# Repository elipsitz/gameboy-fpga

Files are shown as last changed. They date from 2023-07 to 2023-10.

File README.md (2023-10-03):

# FPGA Game Boy Emulator

This repository contains a Game Boy / Game Boy Color emulator, written in [Chisel](https://www.chisel-lang.org/), that can be run on an FPGA. Read the full writeup [here](https://eli.lipsitz.net/posts/fpga-gameboy-emulator/).

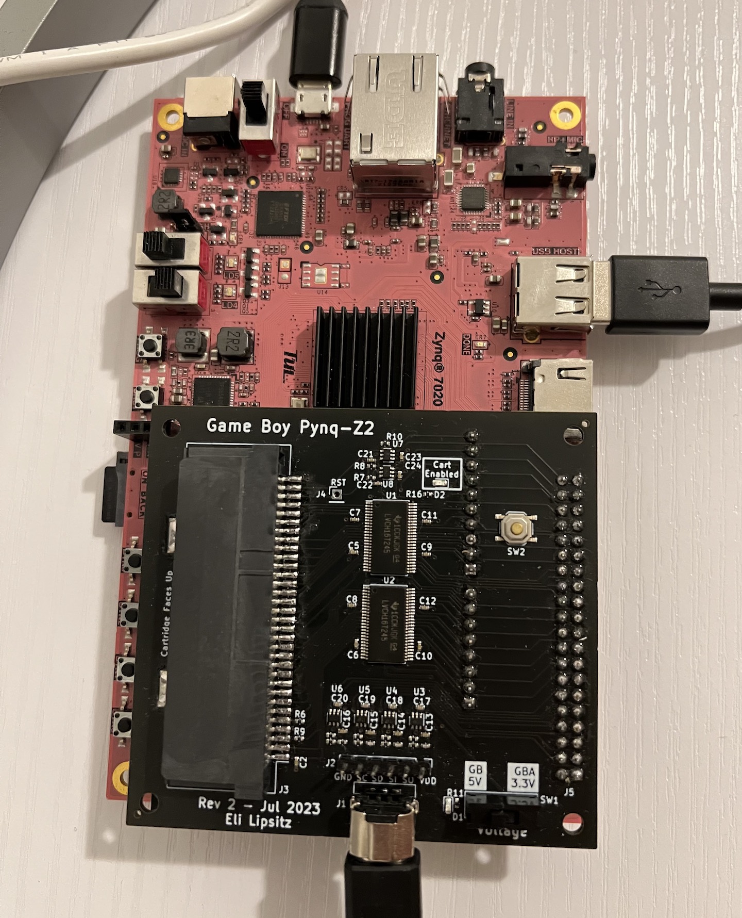
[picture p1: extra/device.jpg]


Currently, only the Pynq-Z2 is supported, although the core of the emulator should be able to be used on any FPGA with sufficient resources.

## Building

A precompiled bitstream is available under Releases.

### Setup

#### Install Vivado

Currently this project uses Vivado 2020.2. The free edition is sufficient. Make sure to install with support for Zynq-7000 SoCs.

Install the [Pynq-Z2 Vivado board files](https://pynq.readthedocs.io/en/latest/overlay_design_methodology/board_settings.html).

Additionally, you should set up a shared IP cache to speed up synthesis of Xilinx IP:
1. Create the `~/vivado_ip_cache` directory (could be located somewhere else).
2. Create the file `~/.Xilinx/Vivado/Vivado_init.tcl`
3. In that file, add `set_param project.defaultIPCacheSetting /home/eli/vivado_ip_cache/` (substituting the absolute path to the IP cache directory).

#### Install other tools

You'll need to install JDK 8 or later, and [Scala Build Tool (`sbt`)](https://www.scala-sbt.org/download.html). Additionally, install [FuseSoC](https://github.com/olofk/fusesoc).

### Building the bitstream

From the top-level directory:

```
fusesoc --cores-root . run --build --target=pynq_z2 elipsitz:gameboy:gameboy
```

This will generate a `.bit` and `.hwh` file, which need to be accessible to the PS Python code.

## Running

### Setup

Install Pynq Linux on the Pynq-Z2, and install the pip packages listed in `python/requirements.txt`.

Transfer the `gameboy_ps` Python module (located in the `python` directory) to the Pynq-Z2.

Place the `gameboy.bit` and `gameboy.hwh` files from the build process in the `gameboy_ps/resources` directory.

### HDMI and Controller

Connect an HDMI cable from the "HDMI OUT" port on the Pynq-Z2 to a monitor or TV.

Attach an Xbox-compatible controller to the USB port of the Pynq-Z2.

### Running 

As root, run `python3 -m gameboy_ps <path to ROM directory>`, passing the path to the directory containing ROM files.

The program will load the bitstream to the PL. It takes a few seconds to load all of the Pynq libraries, but the main menu should soon show up on the display.

Warning: the audio output can be quite loud. Start at the lowest setting on the monitor/TV and increase it as needed.

## Building the cartridge adapter board

To play physical cartridges, you'll need to assemble the adapter board. KiCad board files can be found in the `pcb/pynq_adapter_rev2` directory. The schematic is pre-populated with LCSC part numbers for easy assembly at JLCPCB.

You'll need to add a few components yourself. These are all easy to solder:

* A 2x20 0.1mm female pin header (e.g. [this one](https://www.adafruit.com/product/2222)). These are used for Raspberry Pi HATs, so they're pretty easy to find.
* A SPDT slide switch such as the [EG1218](https://octopart.com/search?q=EG1218), or just a 1x3 strip of 0.1mm male pin header and a jumper.
* A GBA SP slot (such as [this one](https://handheldlegend.com/products/game-boy-cartridge-slot)). These can be found quite cheaply on eBay or Aliexpress as well. They're all pretty much the same.
* If desired, a GBA link port (e.g. [this one](https://handheldlegend.com/products/game-boy-advance-ext-link-port)). These can also be found easily from other sources.

The other parts are relatively small, so I don't recommend hand soldering the board. However, if you want to assemble the whole thing yourself, in addition to assorted resistors and capacitors, you'll also need:

* 6x [74LVC1T45DCK](https://octopart.com/search?q=74LVC1T45DCK) 1-bit level shifters.
* 2x [74LVCH16T245DGGR](https://octopart.com/search?q=74LVCH16T245DGGR) 16-bit level shifters. The non 'H' version should work as well, but the 'H' (bus hold) version is preferable.

## Appendix

### Getting Xbox controller to work on Pynq-Z2

This needs the `xpad` and `joydev` drivers. Pynq Linux isn't built with them. If you're running Pynq Linux with kernel `5.15.19-xilinx-v2022.1`, prebuilt kernel modules can be found in the `extra` directory in the repository. Otherwise, to build loadable kernel modules from scratch:

On the Pynq-Z2, go to `/lib/modules/5.15.19-xilinx-v2022.1/build`.

Download the right version of [`xpad.c`](https://raw.githubusercontent.com/torvalds/linux/v5.15/drivers/input/joystick/xpad.c)
to `drivers/input/joystick/xpad.c`.

And do the same with [`joydev.c`](https://raw.githubusercontent.com/torvalds/linux/v5.15/drivers/input/joydev.c), to `drivers/input/joydev.c`.

The build commands in `/lib/modules` need to run with `sudo` due to permissions issues.

Do `sudo make menuconfig` and set:

* `Device Drivers --> Input device support --> Joystick interface` to `M` (for 'module')
* `Device Drivers --> Input device support --> Joysticks/gamepads --> X-box Gamepad support` to `M` (for 'module')

Save and exit.

Then build the modules:

```
sudo make scripts
sudo make distclean
sudo make prepare
sudo make modules_prepare

sudo make -C . M=drivers/input/ joydev.ko
sudo make -C . M=drivers/input/joystick xpad.ko
```

Install the modules so that they'll be loaded automatically on boot.
Copy the `.ko` files to `/usr/lib/modules/$(uname -r)/kernel/`, and append
to `/etc/modules`:

```
joydev
xpad
```

Alternatively, use `insmod <modules>.ko` to load them once.

Make sure the `xilinx` user is in the group `input`:
`sudo usermod -a -G input xilinx` (and re-login)

Install the Python library with `sudo pip3 install xbox360controller`

Create the device nodes if needed: https://docs.kernel.org/input/joydev/joystick.html#device-nodes

```
cd /dev
rm js*
mkdir input
mknod input/js0 c 13 0
mknod input/js1 c 13 1
mknod input/js2 c 13 2
mknod input/js3 c 13 3
ln -s input/js0 js0
ln -s input/js1 js1
ln -s input/js2 js2
ln -s input/js3 js3
```

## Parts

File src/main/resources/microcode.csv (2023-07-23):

Label | Comment | Encoding | PcNext | IME | RegRead1Sel | RegRead2Sel | RegWriteSel | RegOp | IncOp | IncReg | AluOp | AluSelA | AluSelB | AluFlagSet | MemEn | MemWr | MemAddrSel | MicroBranch | NextState
NOP |  | 00000000 | - | = | - | - | - | None | - | - | - | - | - | No | - | - | - | Fetch | -
_INVALID |  |  | Same | = | - | - | - | None | No | - | - | - | - | No | No | - | - | Jump | _INVALID
HALT |  | 01110110 | Same | = | - | - | - | None | No | - | - | - | - | No | No | - | - | Jump | HALT
STOP |  | 00010000 | IncOut | = | - | - | - | None | Inc | PC | - | - | - | No | No | - | - | Next | -
#STOP_loop |  |  | Same | = | - | - | - | None | No | - | - | - | - | No | No | - | - | Jump | #STOP_loop
LD r, (HL) |  | 01???110 | Same | = | - | - | Reg8Dest | WriteMem | No | HL | - | - | - | No | Yes | No | Incrementer | Jump | NOP
LD (HL), r |  | 01110??? | Same | = | - | Reg8Src | - | None | No | HL | CopyB | - | Reg2 | No | Yes | Yes | Incrementer | Jump | NOP
LD (HL),n |  | 00110110 | IncOut | = | - | - | W | WriteMem | Inc | PC | - | - | - | No | Yes | No | Incrementer | Next | -
 |  |  | Same | = | - | W | - | None | No | HL | CopyB | - | Reg2 | No | Yes | Yes | Incrementer | Jump | NOP
LD r,r |  | 01?????? | - | = | - | Reg8Src | Reg8Dest | WriteAlu | - | - | CopyB | - | Reg2 | No | - | - | - | Fetch | -
LD r,n |  | 00???110 | IncOut | = | - | - | Reg8Dest | WriteMem | Inc | PC | - | - | - | No | Yes | No | Incrementer | Jump | NOP
LD rr,nn |  | 00??0001 | IncOut | = | - | - | Reg16Lo | WriteMem | Inc | PC | - | - | - | No | Yes | No | Incrementer | Next | -
 |  |  | IncOut | = | - | - | Reg16Hi | WriteMem | Inc | PC | - | - | - | No | Yes | No | Incrementer | Jump | NOP
ldi (HL),A |  | 00100010 | Same | = | - | - | - | None | Inc | HL | CopyA | A | - | No | Yes | Yes | Incrementer | Jump | NOP
ldi A,(HL) |  | 00101010 | Same | = | - | - | A | WriteMem | Inc | HL | - | - | - | No | Yes | No | Incrementer | Jump | NOP
ldd (HL),A |  | 00110010 | Same | = | - | - | - | None | Dec | HL | CopyA | A | - | No | Yes | Yes | Incrementer | Jump | NOP
ldd A,(HL) |  | 00111010 | Same | = | - | - | A | WriteMem | Dec | HL | - | - | - | No | Yes | No | Incrementer | Jump | NOP
ALU A, n |  | 11???110 | IncOut | = | - | - | W | WriteMem | Inc | PC | - | - | - | No | Yes | No | Incrementer | Next | -
 |  |  | - | = | - | W | A | WriteAlu | - | - | InstAlu | A | Reg2 | All | - | - | - | Fetch | -
ALU A, (HL) |  | 10???110 | Same | = | - | - | W | WriteMem | No | HL | - | - | - | No | Yes | No | Incrementer | Next | -
 |  |  | - | = | - | W | A | WriteAlu | - | - | InstAlu | A | Reg2 | All | - | - | - | Fetch | -
ALU A, r |  | 10?????? | - | = | - | Reg8Src | A | WriteAlu | - | - | InstAlu | A | Reg2 | All | - | - | - | Fetch | -
JP nn | little endian address | 11000011 | IncOut | = | - | - | Z | WriteMem | Inc | PC | - | - | - | No | Yes | No | Incrementer | Next | -
 |  |  | IncOut | = | - | - | W | WriteMem | Inc | PC | - | - | - | No | Yes | No | Incrementer | Next | -
#PC=WZ |  |  | IncOut | = | - | - | - | None | No | WZ | - | - | - | No | No | - | - | Jump | NOP
JP HL |  | 11101001 | IncOut | = | - | - | - | None | IncNoWrite | HL | - | - | - | No | - | - | Incrementer | Fetch* | -
JP f,nn | Conditional | 110??010 | IncOut | = | - | - | Z | WriteMem | Inc | PC | - | - | - | No | Yes | No | Incrementer | Next | -
 |  |  | IncOut | = | - | - | W | WriteMem | Inc | PC | - | - | - | No | Yes | No | Incrementer | Cond | #PC=WZ
 |  |  | - | = | - | - | - | None | - | - | - | - | - | No | - | - | - | Fetch | -
LD (rr), A |  | 00??0010 | Same | = | - | - | - | None | No | Inst16 | CopyA | A | - | No | Yes | Yes | Incrementer | Jump | NOP
LD A, (rr) |  | 00??1010 | Same | = | - | - | A | WriteMem | No | Inst16 | - | - | - | No | Yes | No | Incrementer | Jump | NOP
LD (nn), A |  | 11101010 | IncOut | = | - | - | Z | WriteMem | Inc | PC | - | - | - | No | Yes | No | Incrementer | Next | -
 |  |  | IncOut | = | - | - | W | WriteMem | Inc | PC | - | - | - | No | Yes | No | Incrementer | Next | -
 |  |  | Same | = | - | - | - | None | No | WZ | CopyA | A | - | No | Yes | Yes | Incrementer | Jump | NOP
LD A, (nn) |  | 11111010 | IncOut | = | - | - | Z | WriteMem | Inc | PC | - | - | - | No | Yes | No | Incrementer | Next | -
 |  |  | IncOut | = | - | - | W | WriteMem | Inc | PC | - | - | - | No | Yes | No | Incrementer | Next | -
 |  |  | Same | = | - | - | A | WriteMem | No | WZ | - | - | - | No | Yes | No | Incrementer | Jump | NOP
LD (FF00 + n), A |  | 11100000 | IncOut | = | - | - | W | WriteMem | Inc | PC | - | - | - | No | Yes | No | Incrementer | Next | -
 |  |  | Same | = | - | W | - | None | No | - | CopyA | A | - | No | Yes | Yes | High | Jump | NOP
LD (FF00 + C), A |  | 11100010 | Same | = | - | C | - | None | No | - | CopyA | A | - | No | Yes | Yes | High | Jump | NOP
LD A, (FF00 + n) |  | 11110000 | IncOut | = | - | - | W | WriteMem | Inc | PC | - | - | - | No | Yes | No | Incrementer | Next | -
 |  |  | Same | = | - | W | A | WriteMem | No | - | - | - | - | No | Yes | No | High | Jump | NOP
LD A, (FF00 + C) |  | 11110010 | Same | = | - | C | A | WriteMem | No | - | - | - | - | No | Yes | No | High | Jump | NOP
INC rr |  | 00??0011 | Same | = | - | - | - | None | Inc | Inst16 | - | - | - | No | No | - | - | Jump | NOP
DEC rr |  | 00??1011 | Same | = | - | - | - | None | Dec | Inst16 | - | - | - | No | No | - | - | Jump | NOP
LD (nn), SP |  | 00001000 | IncOut | = | - | - | Z | WriteMem | Inc | PC | - | - | - | No | Yes | No | Incrementer | Next | -
 |  |  | IncOut | = | - | - | W | WriteMem | Inc | PC | - | - | - | No | Yes | No | Incrementer | Next | -
 |  |  | Same | = | - | SP_Lo | - | None | Inc | WZ | CopyB | - | Reg2 | No | Yes | Yes | Incrementer | Next | -
 |  |  | Same | = | - | SP_Hi | - | None | Inc | WZ | CopyB | - | Reg2 | No | Yes | Yes | Incrementer | Jump | NOP
LD SP, HL |  | 11111001 | Same | = | - | L | SP_Lo | WriteAlu | No | - | CopyB | - | Reg2 | No | No | - | - | Next | -
 |  |  | - | = | - | H | SP_Hi | WriteAlu | - | - | CopyB | - | Reg2 | No | - | - | - | Fetch | -
PUSH AF |  | 11110101 | Same | = | - | - | - | None | Dec | SP | - | - | - | No | No | No | - | Next | -
 |  |  | Same | = | - | A | - | None | Dec | SP | CopyB | - | Reg2 | No | Yes | Yes | Incrementer | Next | -
 |  |  | Same | = | - | F | - | None | No | SP | CopyB | - | Reg2 | No | Yes | Yes | Incrementer | Jump | NOP
POP AF |  | 11110001 | Same | = | - | - | F | WriteMem | Inc | SP | CopyB | - | Reg2 | No | Yes | No | Incrementer | Next | -
 |  |  | Same | = | - | - | A | WriteMem | Inc | SP | CopyB | - | Reg2 | No | Yes | No | Incrementer | Jump | NOP
PUSH rr |  | 11??0101 | Same | = | - | - | - | None | Dec | SP | - | - | - | No | No | No | - | Next | -
 |  |  | Same | = | - | Reg16Hi | - | None | Dec | SP | CopyB | - | Reg2 | No | Yes | Yes | Incrementer | Next | -
 |  |  | Same | = | - | Reg16Lo | - | None | No | SP | CopyB | - | Reg2 | No | Yes | Yes | Incrementer | Jump | NOP
POP rr |  | 11??0001 | Same | = | - | - | Reg16Lo | WriteMem | Inc | SP | - | - | - | No | Yes | No | Incrementer | Next | -
 |  |  | Same | = | - | - | Reg16Hi | WriteMem | Inc | SP | - | - | - | No | Yes | No | Incrementer | Jump | NOP
ADD HL,rr | 16-bit add | 00??1001 | Same | = | L | Reg16Lo | L | WriteAlu | No | - | AddLo | Reg1 | Reg2 | No | No | - | - | Next | -
 |  |  | - | = | H | Reg16Hi | H | WriteAlu | - | - | AddHi | Reg1 | Reg2 | -*** | - | - | - | Fetch | -
ADD SP,dd |  | 11101000 | IncOut | = | - | - | W | WriteMem | Inc | PC | - | - | - | No | Yes | No | Incrementer | Next | -
 |  |  | Same | = | SP_Lo | W | SP_Lo | WriteAlu | No | - | AddLo | Reg1 | Reg2 | 0*** | No | - | - | Next | -
 |  |  | Same | = | SP_Hi | W | SP_Hi | WriteAlu | No | - | AddHi | Reg1 | SignReg2 | No | No | - | - | Jump | NOP
ld HL,SP+dd |  | 11111000 | IncOut | = | - | - | W | WriteMem | Inc | PC | - | - | - | No | Yes | No | Incrementer | Next | -
 |  |  | Same | = | SP_Lo | W | L | WriteAlu | No | - | AddLo | Reg1 | Reg2 | 0*** | No | - | - | Next | -
 |  |  | - | = | SP_Hi | W | H | WriteAlu | - | - | AddHi | Reg1 | SignReg2 | No | - | - | - | Fetch | -
JR e |  | 00011000 | IncOut | = | - | - | W | WriteMem | Inc | PC | - | - | - | No | Yes | No | Incrementer | Next | -
#PC+=W |  |  | Same | = | PC_Lo | W | PC_Lo | WriteAlu | No | - | AddLo | Reg1 | Reg2 | No | No | - | - | Next | -
 | Mem MemAddr to be the new PC, and need to increment PC |  | IncOut | = | PC_Hi | W | PC_Hi | WriteAlu | IncNoWrite | PC_ALU | AddHi | Reg1 | SignReg2 | No | Yes | No | Incrementer | Fetch* | -
JR c,e | Conditional | 001??000 | IncOut | = | - | - | W | WriteMem | Inc | PC | - | - | - | No | Yes | No | Incrementer | Cond | #PC+=W
 |  |  | - | = | - | - | - | None | - | - | - | - | - | No | - | - | - | Fetch | -
CALL nn |  | 11001101 | IncOut | = | - | - | Z | WriteMem | Inc | PC | - | - | - | No | Yes | No | Incrementer | Next | -
 |  |  | IncOut | = | - | - | W | WriteMem | Inc | PC | - | - | - | No | Yes | No | Incrementer | Next | -
#CALL_end |  |  | Same | = | - | - | - | None | Dec | SP | - | - | - | No | No | No | - | Next | -
 |  |  | Same | = | - | PC_Hi | - | None | Dec | SP | CopyB | - | Reg2 | No | Yes | Yes | Incrementer | Next | -
 |  |  | Same | = | - | PC_Lo | - | None | No | SP | CopyB | - | Reg2 | No | Yes | Yes | Incrementer | Next | -
 |  |  | IncOut | = | - | - | - | None | IncNoWrite | WZ | - | - | - | No | - | - | Incrementer | Fetch* | -
CALL cc, nn | Conditional | 110??100 | IncOut | = | - | - | Z | WriteMem | Inc | PC | - | - | - | No | Yes | No | Incrementer | Next | -
 |  |  | IncOut | = | - | - | W | WriteMem | Inc | PC | - | - | - | No | Yes | No | Incrementer | Cond | #CALL_end
 |  |  | - | = | - | - | - | None | - | - | - | - | - | No | - | - | - | Fetch | -
RET |  | 11001001 | Same | = | - | - | PC_Lo | WriteMem | Inc | SP | - | - | - | No | Yes | No | Incrementer | Next | -
 |  |  | Same | = | - | - | PC_Hi | WriteMem | Inc | SP | - | - | - | No | Yes | No | Incrementer | Next | -
 | Extra NOP |  | Same | = | - | - | - | None | No | - | - | - | - | No | No | - | - | Jump | NOP
RET cc | Conditional | 110??000 | Same | = | - | - | - | None | No | - | - | - | - | No | No | - | - | Cond | RET
 |  |  | - | = | - | - | - | None | - | - | - | - | - | No | - | - | - | Fetch | -
RETI | RET + enable interrupts | 11011001 | Same | = | - | - | PC_Lo | WriteMem | Inc | SP | - | - | - | No | Yes | No | Incrementer | Next | -
 |  |  | Same | = | - | - | PC_Hi | WriteMem | Inc | SP | - | - | - | No | Yes | No | Incrementer | Next | -
 | Extra NOP |  | Same | En | - | - | - | None | No | - | - | - | - | No | No | - | - | Jump | NOP
INC (HL) |  | 00110100 | Same | = | - | - | W | WriteMem | No | HL | - | - | - | No | Yes | No | Incrementer | Next | -
 |  |  | Same | = | - | W | - | None | No | HL | IncB | - | Reg2 | All | Yes | Yes | Incrementer | Jump | NOP
INC r |  | 00???100 | - | = | - | Reg8Dest | Reg8Dest | WriteAlu | - | - | IncB | - | Reg2 | All | - | - | - | Fetch | -
DEC (HL) |  | 00110101 | Same | = | - | - | W | WriteMem | No | HL | - | - | - | No | Yes | No | Incrementer | Next | -
 |  |  | Same | = | - | W | - | None | No | HL | DecB | - | Reg2 | All | Yes | Yes | Incrementer | Jump | NOP
DEC r |  | 00???101 | - | = | - | Reg8Dest | Reg8Dest | WriteAlu | - | - | DecB | - | Reg2 | All | - | - | - | Fetch | -
ALU unary | accumulator/flag ops | 00???111 | - | = | - | - | A | WriteAlu | - | - | InstAcc | A | Reg2 | All | - | - | - | Fetch | -
CB_PREFIX | CB prefix | 11001011 | IncOut | = | - | - | - | None | Inc | PC | - | - | - | No | Yes | No | Incrementer | DispatchCB | -
CB_ALU (HL) | CB shift / rotates | CB_00???110 | Same | = | - | - | W | WriteMem | No | HL | - | - | - | No | Yes | No | Incrementer | Next | -
 |  |  | Same | = | - | W | - | None | No | HL | InstCB | - | Reg2 | All | Yes | Yes | Incrementer | Jump | NOP
CB_ALU r | CB shift / rotates | CB_00?????? | - | = | - | Reg8Src | Reg8Src | WriteAlu | - | - | InstCB | - | Reg2 | All | - | - | - | Fetch | -
BIT (HL) | No (HL) writeback | CB_01???110 | Same | = | - | - | W | WriteMem | No | HL | - | - | - | No | Yes | No | Incrementer | Next | -
 |  |  | - | = | - | W | - | None | - | - | InstBit | - | Reg2 | All | - | - | - | Fetch | -
CB_BIT (HL) |  | CB_?????110 | Same | = | - | - | W | WriteMem | No | HL | - | - | - | No | Yes | No | Incrementer | Next | -
 |  |  | Same | = | - | W | - | None | No | HL | InstBit | - | Reg2 | All | Yes | Yes | Incrementer | Jump | NOP
CB_BIT r |  | CB_???????? | - | = | - | Reg8Src | Reg8Src | WriteAlu | - | - | InstBit | - | Reg2 | All | - | - | - | Fetch | -
EI | Enable interrupts | 11111011 | - | En | - | - | - | None | - | - | - | - | - | No | - | - | - | Fetch | -
DI | Disable interrupts | 11110011 | - | Dis | - | - | - | None | - | - | - | - | - | No | - | - | - | Fetch | -
RST vec |  | 11???111 | Same | = | - | - | - | None | Dec | SP | - | - | - | No | No | No | - | Next | -
 |  |  | Same | = | - | PC_Hi | - | None | Dec | SP | CopyB | - | Reg2 | No | Yes | Yes | Incrementer | Next | -
 |  |  | RstAddr | = | - | PC_Lo | - | None | No | SP | CopyB | - | Reg2 | No | Yes | Yes | Incrementer | Jump | NOP
#Interrupt | decrement PC |  | IncOut | Dis | - | - | - | None | Dec | PC | - | - | - | No | No | No | - | Next | -
#Interrupt_keepPC | decrement SP |  | Same | Dis | - | - | - | None | Dec | SP | - | - | - | No | No | No | - | Next | -
 | push PC hi |  | Same | = | - | PC_Hi | - | None | Dec | SP | CopyB | - | Reg2 | No | Yes | Yes | Incrementer | Next | -
 | push PC, jump |  | Interrupt | = | - | PC_Lo | - | None | No | SP | CopyB | - | Reg2 | No | Yes | Yes | Incrementer | Jump | NOP

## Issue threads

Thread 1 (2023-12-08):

CacheMetadataError when loading overlay

rderi, 2023-12-08:
I have been trying to run the emulator on my PYNQ-Z2 board, but before the overlay loads, I keep encountering the same `CacheMetadataError`. I am using this repository for a class project, and I would really appreciate some help troubleshooting. The program's output is:

```
[2022-10-22 03:55:53,880][INFO] Loading Pynq libraries...
[2022-10-22 03:56:03,622][INFO] Finished loading Pynq libraries
[2022-10-22 03:56:04,176][INFO] Loading overlay...
[2022-10-22 03:56:04,190][DEBUG] Using selector: EpollSelector
Traceback (most recent call last):
  File "/usr/local/share/pynq-venv/lib/python3.10/site-packages/pynq/pl_server/embedded_device.py", line 252, in get_parser
    parser = self._get_cache()
  File "/usr/local/share/pynq-venv/lib/python3.10/site-packages/pynq/pl_server/embedded_device.py", line 228, in _get_cache
    raise CacheMetadataError(f"No cached metadata present")
pynq.pl_server.embedded_device.CacheMetadataError: No cached metadata present

During handling of the above exception, another exception occurred:

Traceback (most recent call last):
  File "/usr/lib/python3.10/runpy.py", line 196, in _run_module_as_main
    return _run_code(code, main_globals, None,
  File "/usr/lib/python3.10/runpy.py", line 86, in _run_code
    exec(code, run_globals)
  File "/home/xilinx/final/gameboy_ps/__main__.py", line 17, in <module>
    system = system.System(rom_directory)
  File "/home/xilinx/final/gameboy_ps/system.py", line 15, in __init__
    self.gameboy = Gameboy()
  File "/home/xilinx/final/gameboy_ps/gameboy.py", line 72, in __init__
    self.overlay = Overlay(str(overlay_path))
  File "/usr/local/share/pynq-venv/lib/python3.10/site-packages/pynq/overlay.py", line 319, in __init__
    self.device.set_bitfile_name(self.bitfile_name)
  File "/usr/local/share/pynq-venv/lib/python3.10/site-packages/pynq/pl_server/device.py", line 118, in set_bitfile_name
    self.parser = self.get_bitfile_metadata(self.bitfile_name)
  File "/usr/local/share/pynq-venv/lib/python3.10/site-packages/pynq/pl_server/embedded_device.py", line 690, in get_bitfile_metadata
    parser = _get_bitstream_handler(bitfile_name).get_parser(partial=partial)
  File "/usr/local/share/pynq-venv/lib/python3.10/site-packages/pynq/pl_server/embedded_device.py", line 254, in get_parser
    parser = RuntimeMetadataParser(Metadata(input=self._filepath.with_suffix(".hwh")))
  File "/usr/local/share/pynq-venv/lib/python3.10/site-packages/pynqmetadata/frontends/metadata.py", line 40, in Metadata
    return HwhFrontend(_hwhfile=input)
  File "<string>", line 25, in __init__
  File "/usr/local/share/pynq-venv/lib/python3.10/site-packages/pynqmetadata/frontends/hwh_frontend.py", line 219, in __post_init__
    self.parse()
  File "/usr/local/share/pynq-venv/lib/python3.10/site-packages/pynqmetadata/frontends/hwh_frontend.py", line 240, in parse
    self.resolve_addressing()
  File "/usr/local/share/pynq-venv/lib/python3.10/site-packages/pynqmetadata/frontends/hwh_frontend.py", line 596, in resolve_addressing
    self._resolve_subordinate_addressing()
  File "/usr/local/share/pynq-venv/lib/python3.10/site-packages/pynqmetadata/frontends/hwh_frontend.py", line 452, in _resolve_subordinate_addressing
    core = self.blocks[i.get("INSTANCE")]
KeyError: 'M_AXI_0'
```
<br>

_Additional info:_
- Using v3.0.1 of the PYNQ-Z2 SD card image
- Using the precompiled bitstream
- Tested with multiple ROM files
- Followed set-up instructions:  moved `gameboy.bit` and `gameboy.hwh`  to `gameboy_ps/resources`; loaded `xpad` and `joydev` drivers from the repo's `extra` directory; installed required Python packages

elipsitz, 2023-12-08:
Oh, this sounds familiar. I think the Pynq libraries distributed with v3.0.1 are slightly outdated.

I’m pretty sure you need this commit: https://github.com/Xilinx/PYNQ-Metadata/commit/d67f1bf9d020ec3432de2742c108fa8dc442b0f2

You can try temporarily modifying /usr/local/share/pynq-venv/lib/python3.10/site-packages/pynqmetadata/frontends/hwh_frontend.py with the changes and see if that fixes it. And then if it does, do a proper pip install from that repo. Let me know if that works, and I can update the instructions. Hopefully I didn’t have to make any other changes to the Pynq libraries, but I’ll try to see.

Out of curiosity, what’s the class project?

bzob, 2024-12-02:
I had the same problem. I changed hwh_frontend.py according to what @elipsitz mentioned above and that fixed it.

rderi, 2024-12-02:
Sorry, I forgot to get back—the fix also worked for me.

Closed 2024-12-02.

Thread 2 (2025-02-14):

How many times do you choose PCB thickness?

kinaka, 2025-02-14:
Could you please advise on the appropriate thickness to choose when printing a PCB?

elipsitz, 2025-02-15:
Just added the info to docs/building.md. It's 1.6mm.

Completed in be1d65f

Closed 2025-02-15.

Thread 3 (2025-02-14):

Blog source?

JohnVeness, 2025-02-14:
Hi, is the source for your blog (https://eli.lipsitz.net/) available somewhere? I noticed a couple of typos I'd love to fix! Many thanks for this very interesting-looking project.

elipsitz, 2025-02-14:
I haven’t published the source for my website, but if you want to point out the typos I’d be happy to fix them.

JohnVeness, 2025-02-14:
OK thanks, here goes!:

1, In "I briefly considered using an ultra-low power, always on microcontroller to act as a custom PMIC provide power switch functionality" should probably be "...PMIC to provide power..." or "...PMIC providing power...".

2, In "accessing DRAM requires sending commands to “activate” (open) a rows" should be "a row".

3, Picky of me, but Aliexpress should be AliExpress!

4, "These run at different voltages and use different protocols, so the device need some way of determining which type of cartridge is inserted" should be "needed".

5, "I chose this because it was 1) I2C (no additional pins required) 2) cheap and 3) readily available from JLCPCB" should have commas before and after "2) cheap".

6, "Eventually, I laid out all of the components, connected them, ensured all of the nets were labeled, and ran KiCad’s electrical rules checker (ERC) to find obvious mistakes, I moved on to layout" should probably be something like "before moving on to layout".

7, Again, picky of me, but "I ended up being able to do this routing with a 6-layer PCB (three signal, two ground, one power), with 0.1mm track width and spacing, and 0.4/0.25 mm vias" should probably be "0.4/0.25mm vias" for consistent spacing.

8, "Next, I updated my testing FPGA bitstream with a to output a test pattern over the [LCD parallel interface (“DPI”)" is missing something between "a" and "to". Or maybe just drop "with a".

9, "The bare board just wasn’t cutting it anymore, and the taped LCD module, loose speakers, and rubber-banded battery was fragile" should be "were fragile".

10, "ARM7TDMI block diagram (source: ARM7TDMI Technical Reference Manual" is missing a closing bracket.

11, "The Game Boy cartridge bus is asynchronous: the game outputs the 16-bit address (64 KiB address space) on one set of pins and lowers the nRD pin, some time later, the 8-bit read data from the ROM stabilizes on a separate set of pins" should probably have a semi-colon instead of the comma before "some time later".

12, "During the emulator development, I had used various test ROMS (mentioned before) to test basic functionality in isolation" should be "ROMs".

13, "I improved the rumble circuit to be more reponsive" should be "responsive".

Hope this is OK!

elipsitz, 2025-02-15:
Thanks! Updated the post.

JohnVeness, 2025-02-15:
Thanks, looks good, and I appreciate that you improved some of my suggestions!

Closed 2025-02-15.

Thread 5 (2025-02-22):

Gerber/Drill/BOM/Placement files

MitchOgden, 2025-02-22:
Hey there,

Any chance you could add the Gerber/Drill/BOM/Placement files you used to produce the PCB? I've been having issues getting the placement that I export from KiCad to translate correctly on import into JLCPCB.

Thank you!

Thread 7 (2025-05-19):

STL Sources?

finger563, 2025-05-19:
Hey! I love your project and I really like your 3D shell design. I've got my own design I've been working on for a while (https://github.com/esp-cpp/esp-box-emu) and I'd love to make a remix of your shell design which is compatible with the ESP32-S3-BOX devkit that my project is based around. If that's not something you're willing to do, that's OK :)

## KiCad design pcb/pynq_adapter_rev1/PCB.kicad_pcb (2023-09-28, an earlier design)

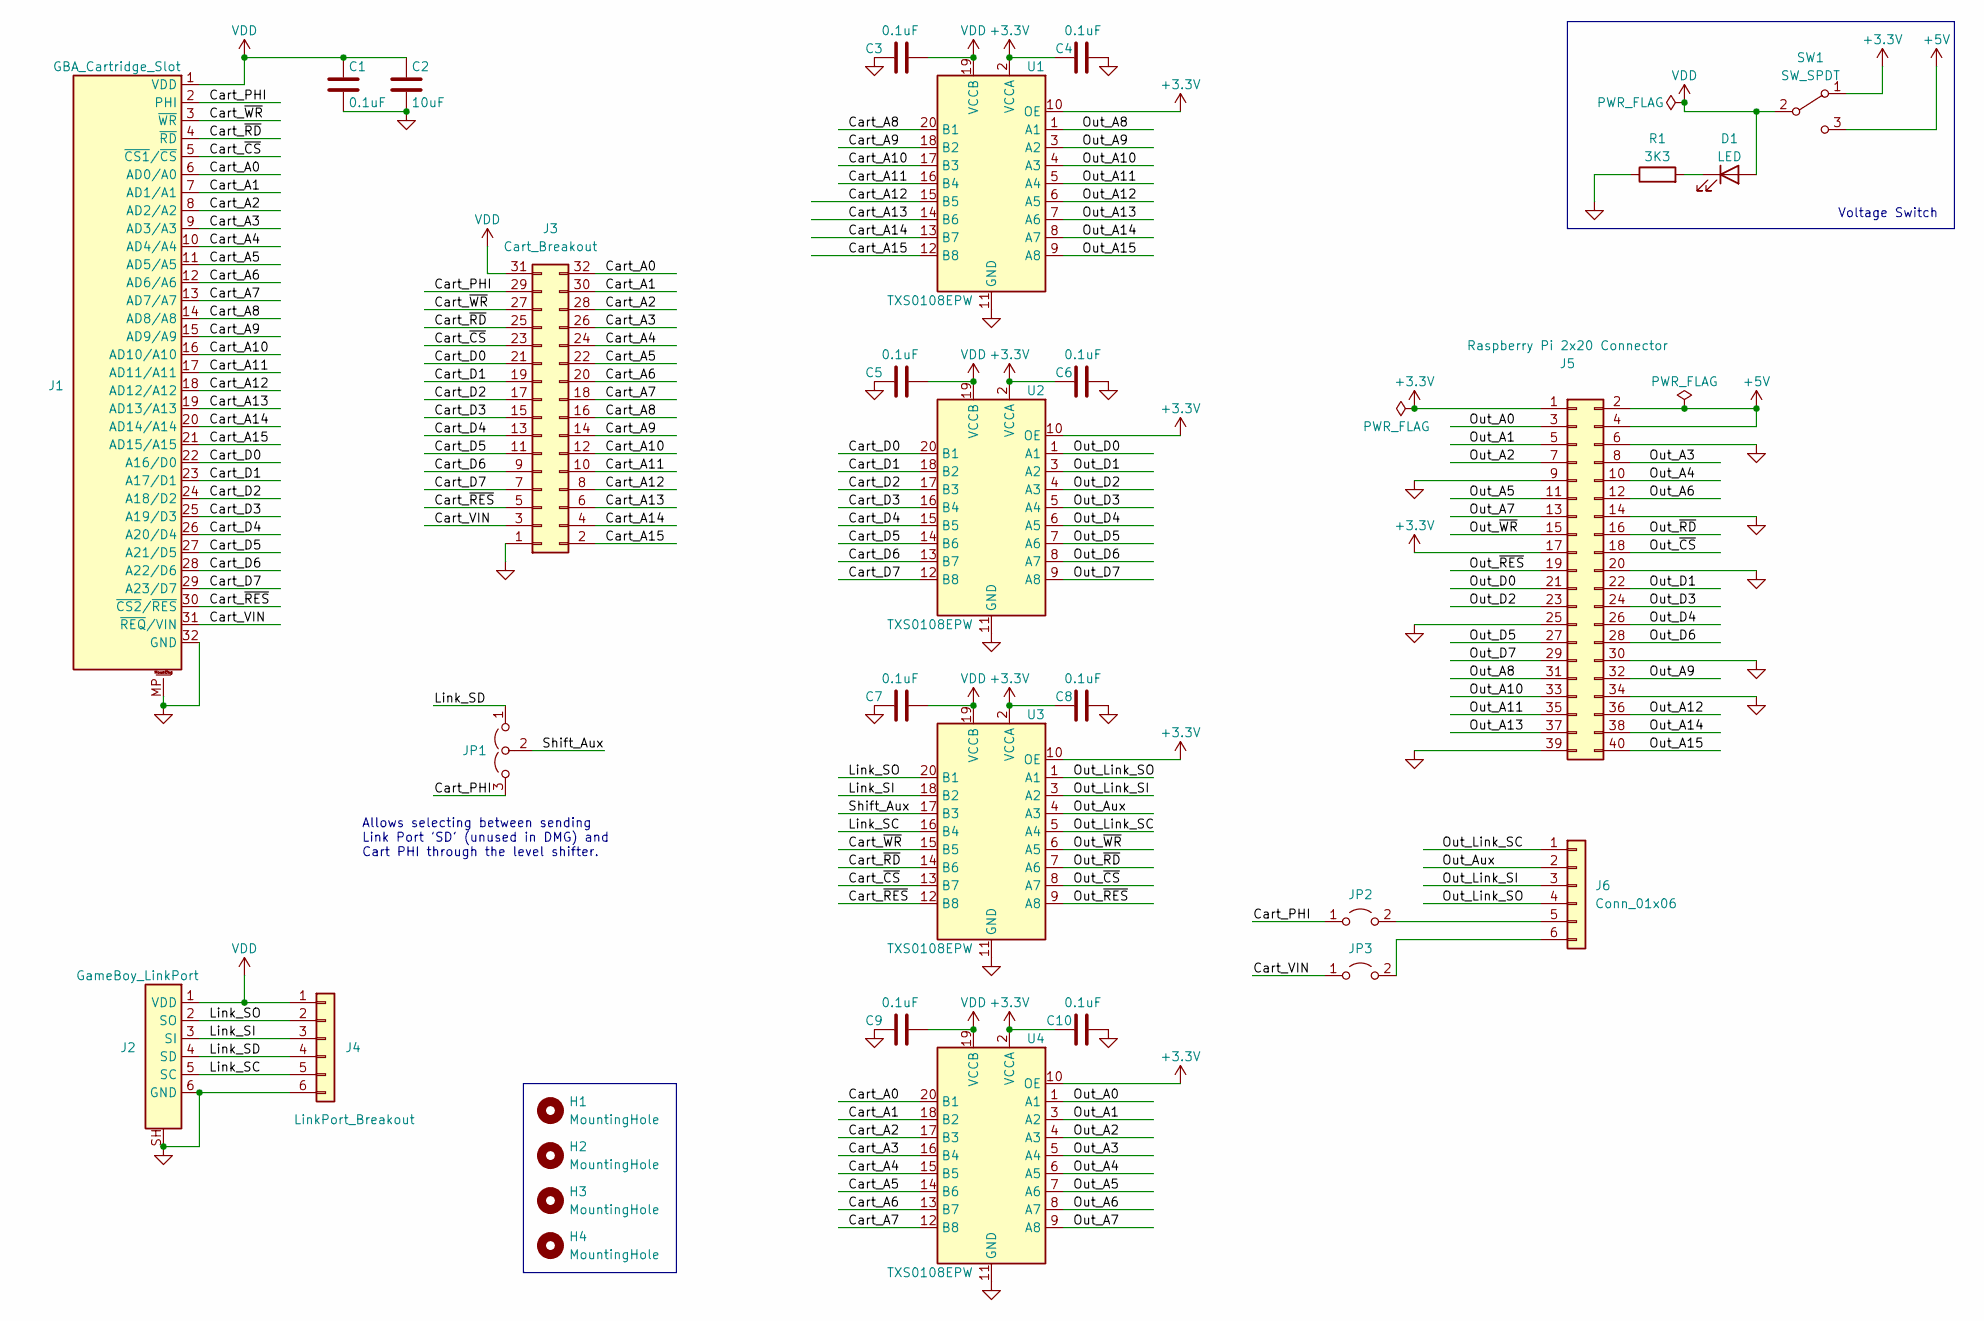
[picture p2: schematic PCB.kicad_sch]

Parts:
C1, C3, C4, C5, C6, C7, C8, C9, C10: 0.1uF; C_0603_1608Metric; LCSC C14663
C2: 10uF; C_1206_3216Metric; LCSC C13585
D1: LED; LED_0603_1608Metric; LCSC C2286
H1, H2, H3, H4: MountingHole; MountingHole_3.2mm_M3
J1: GBA_Cartridge_Slot; GameBoy_Cartridge_AGS_1x32-1MP_P1.50mm_Socket_Horizontal
J2: GameBoy_LinkPort; GameBoy_LinkPort_MGB_Horizontal
J3: Cart_Breakout; PinHeader_2x16_P2.54mm_Vertical
J4: LinkPort_Breakout; PinHeader_1x06_P2.54mm_Vertical
J5: Raspberry Pi 2x20 Connector; PinSocket_2x20_P2.54mm_Vertical
J6: Conn_01x06; PinHeader_1x06_P2.54mm_Vertical
JP1: Jumper_3_Open; PinHeader_1x03_P2.54mm_Vertical
JP2, JP3: Jumper_2_Open; PinHeader_1x02_P2.54mm_Vertical
R1: 3K3; R_0402_1005Metric; LCSC C25890
SW1: SW_SPDT; EG1218
U1, U2, U3, U4: TXS0108EPW; TSSOP-20_4.4x6.5mm_P0.65mm

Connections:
+3.3V: C4.2, C6.2, C8.2, C10.2, J5.1 (GND), J5.17 (3V3), SW1.1 (A), U1.2 (VCCA), U1.10 (OE), U2.2 (VCCA), U2.10 (OE), U3.2 (VCCA), U3.10 (OE), U4.2 (VCCA), U4.10 (OE)
+5V: J5.2 (5V), J5.4 (5V), SW1.3 (C)
/Cart_A0: J1.6 (AD0/A0), J3.32, U4.20 (B1)
/Cart_A1: J1.7 (AD1/A1), J3.30, U4.18 (B2)
/Cart_A2: J1.8 (AD2/A2), J3.28, U4.17 (B3)
/Cart_A3: J1.9 (AD3/A3), J3.26, U4.16 (B4)
/Cart_A4: J1.10 (AD4/A4), J3.24, U4.15 (B5)
/Cart_A5: J1.11 (AD5/A5), J3.22, U4.14 (B6)
/Cart_A6: J1.12 (AD6/A6), J3.20, U4.13 (B7)
/Cart_A7: J1.13 (AD7/A7), J3.18, U4.12 (B8)
/Cart_A8: J1.14 (AD8/A8), J3.16, U1.20 (B1)
/Cart_A9: J1.15 (AD9/A9), J3.14, U1.18 (B2)
/Cart_A10: J1.16 (AD10/A10), J3.12, U1.17 (B3)
/Cart_A11: J1.17 (AD11/A11), J3.10, U1.16 (B4)
/Cart_A12: J1.18 (AD12/A12), J3.8, U1.15 (B5)
/Cart_A13: J1.19 (AD13/A13), J3.6, U1.14 (B6)
/Cart_A14: J1.20 (AD14/A14), J3.4, U1.13 (B7)
/Cart_A15: J1.21 (AD15/A15), J3.2, U1.12 (B8)
/Cart_D0: J1.22 (A16/D0), J3.21, U2.20 (B1)
/Cart_D1: J1.23 (A17/D1), J3.19, U2.18 (B2)
/Cart_D2: J1.24 (A18/D2), J3.17, U2.17 (B3)
/Cart_D3: J1.25 (A19/D3), J3.15, U2.16 (B4)
/Cart_D4: J1.26 (A20/D4), J3.13, U2.15 (B5)
/Cart_D5: J1.27 (A21/D5), J3.11, U2.14 (B6)
/Cart_D6: J1.28 (A22/D6), J3.9, U2.13 (B7)
/Cart_D7: J1.29 (A23/D7), J3.7, U2.12 (B8)
/Cart_PHI: J1.2 (PHI), J3.29, JP1.3 (B), JP2.1 (A)
/Cart_VIN: J1.31 (~REQ/VIN), J3.3, JP3.1 (A)
/Cart_~CS: J1.5 (~CS1/~CS), J3.23, U3.13 (B7)
/Cart_~RD: J1.4 (~RD), J3.25, U3.14 (B6)
/Cart_~RES: J1.30 (~CS2/~RES), J3.5, U3.12 (B8)
/Cart_~WR: J1.3 (~WR), J3.27, U3.15 (B5)
/Link_SC: J2.5 (SC), J4.5, U3.16 (B4)
/Link_SD: J2.4 (SD), J4.4, JP1.1 (A)
/Link_SI: J2.3 (SI), J4.3, U3.18 (B2)
/Link_SO: J2.2 (SO), J4.2, U3.20 (B1)
/Out_A0: J5.3 (Zynq_W18), U4.1 (A1)
/Out_A1: J5.5 (Zynq_W19), U4.3 (A2)
/Out_A2: J5.7 (Zynq_V6), U4.4 (A3)
/Out_A3: J5.8 (Zynq_Y18), U4.5 (A4)
/Out_A4: J5.10 (Zynq_Y19), U4.6 (A5)
/Out_A5: J5.11 (Zynq_U7), U4.7 (A6)
/Out_A6: J5.12 (Zynq_C20), U4.8 (A7)
/Out_A7: J5.13 (Zynq_V7), U4.9 (A8)
/Out_A8: J5.31 (Zynq_Y7), U1.1 (A1)
/Out_A9: J5.32 (Zynq_B20), U1.3 (A2)
/Out_A10: J5.33 (Zynq_W8), U1.4 (A3)
/Out_A11: J5.35 (Zynq_Y8), U1.5 (A4)
/Out_A12: J5.36 (Zynq_B19), U1.6 (A5)
/Out_A13: J5.37 (Zynq_W9), U1.7 (A6)
/Out_A14: J5.38 (Zynq_A20), U1.8 (A7)
/Out_A15: J5.40 (Zynq_Y9), U1.9 (A8)
/Out_Aux: J6.2, U3.4 (A3)
/Out_D0: J5.21 (Zynq_V10), U2.1 (A1)
/Out_D1: J5.22 (Zynq_U19), U2.3 (A2)
/Out_D2: J5.23 (Zynq_W10), U2.4 (A3)
/Out_D3: J5.24 (Zynq_F19), U2.5 (A4)
/Out_D4: J5.26 (Zynq_F20), U2.6 (A5)
/Out_D5: J5.27 (Zynq_Y16), U2.7 (A6)
/Out_D6: J5.28 (Zynq_Y17), U2.8 (A7)
/Out_D7: J5.29 (Zynq_Y6), U2.9 (A8)
/Out_Link_SC: J6.1, U3.5 (A4)
/Out_Link_SI: J6.3, U3.3 (A2)
/Out_Link_SO: J6.4, U3.1 (A1)
/Out_~CS: J5.18 (Zynq_U18), U3.8 (A7)
/Out_~RD: J5.16 (Zynq_W6), U3.7 (A6)
/Out_~RES: J5.19 (Zynq_V8), U3.9 (A8)
/Out_~WR: J5.15 (Zynq_U8), U3.6 (A5)
/Shift_Aux: JP1.2 (C), U3.17 (B3)
GND: C1.2, C2.2, C3.1, C4.1, C5.1, C6.1, C7.1, C8.1, C9.1, C10.1, J1.32 (GND), J1.MP, J2.6 (GND), J2.SH, J3.1, J4.6, J5.6 (GND), J5.9 (GND), J5.14 (GND), J5.20 (GND), J5.25 (GND), J5.30 (GND), J5.34 (GND), J5.39 (GND), R1.1, U1.11 (GND), U2.11 (GND), U3.11 (GND), U4.11 (GND)
unnamed: D1.1 (K), R1.2
unnamed: J6.5, JP2.2 (B)
unnamed: J6.6, JP3.2 (B)
VDD: C1.1, C2.1, C3.2, C5.2, C7.2, C9.2, D1.2 (A), J1.1 (VDD), J2.1 (VDD), J3.31, J4.1, SW1.2 (B), U1.19 (VCCB), U2.19 (VCCB), U3.19 (VCCB), U4.19 (VCCB)

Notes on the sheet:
Voltage Switch
Allows selecting between sending Link Port 'SD' (unused in DMG) and Cart PHI through the level shifter.

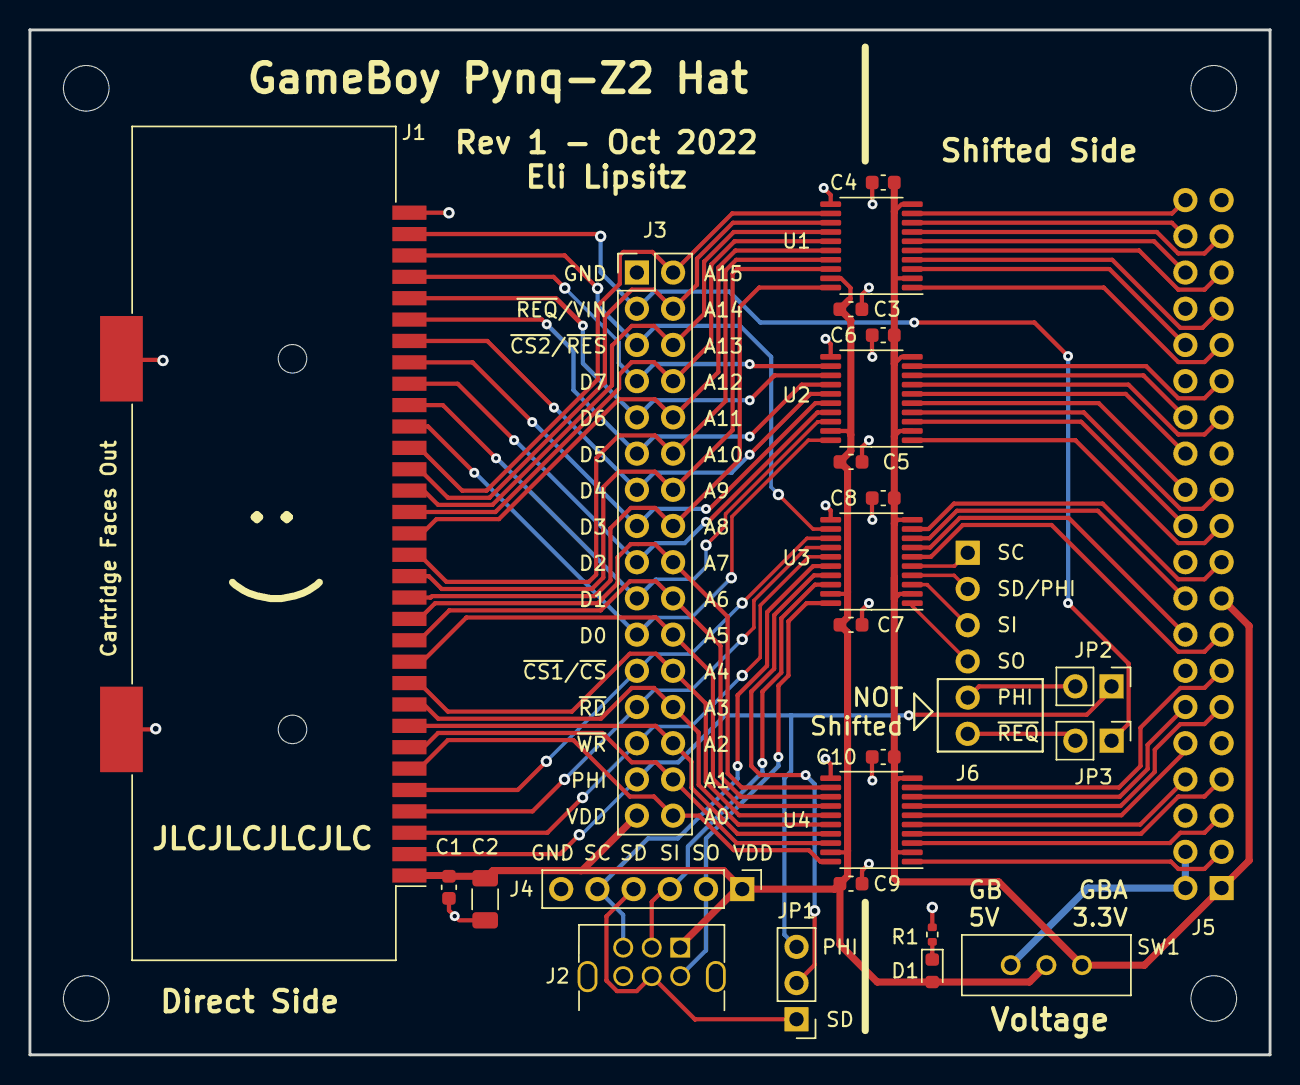
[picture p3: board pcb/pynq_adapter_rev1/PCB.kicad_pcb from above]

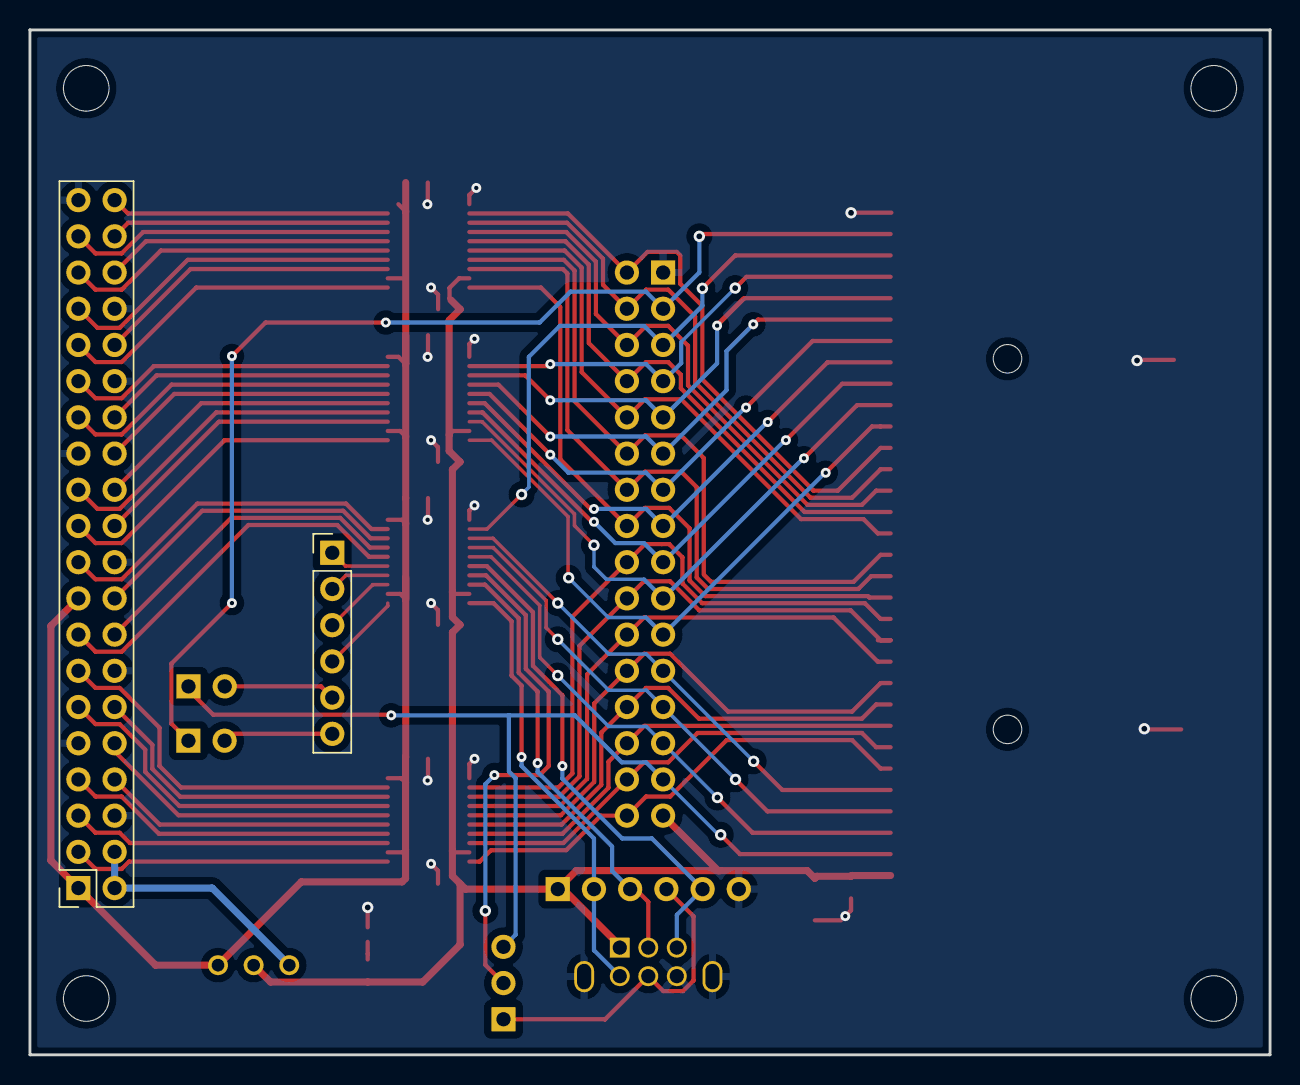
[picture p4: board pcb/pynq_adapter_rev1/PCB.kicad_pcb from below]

Board: 2 copper layers, 87.0 x 71.9 mm, 30 parts (2 on the bottom side), 74 nets.

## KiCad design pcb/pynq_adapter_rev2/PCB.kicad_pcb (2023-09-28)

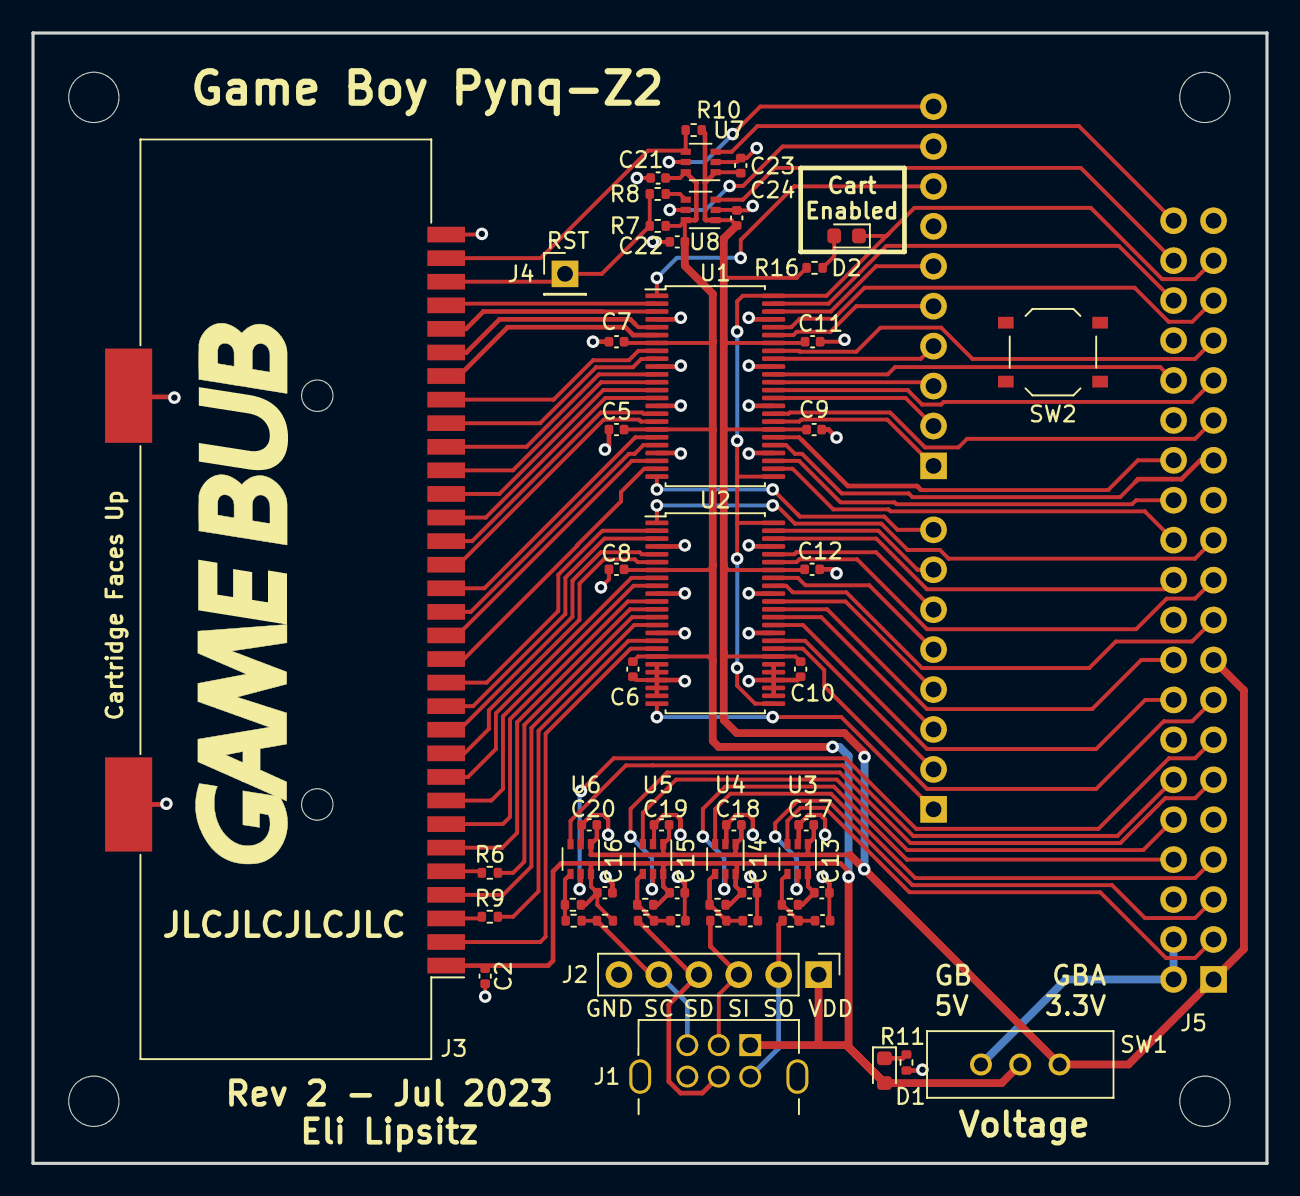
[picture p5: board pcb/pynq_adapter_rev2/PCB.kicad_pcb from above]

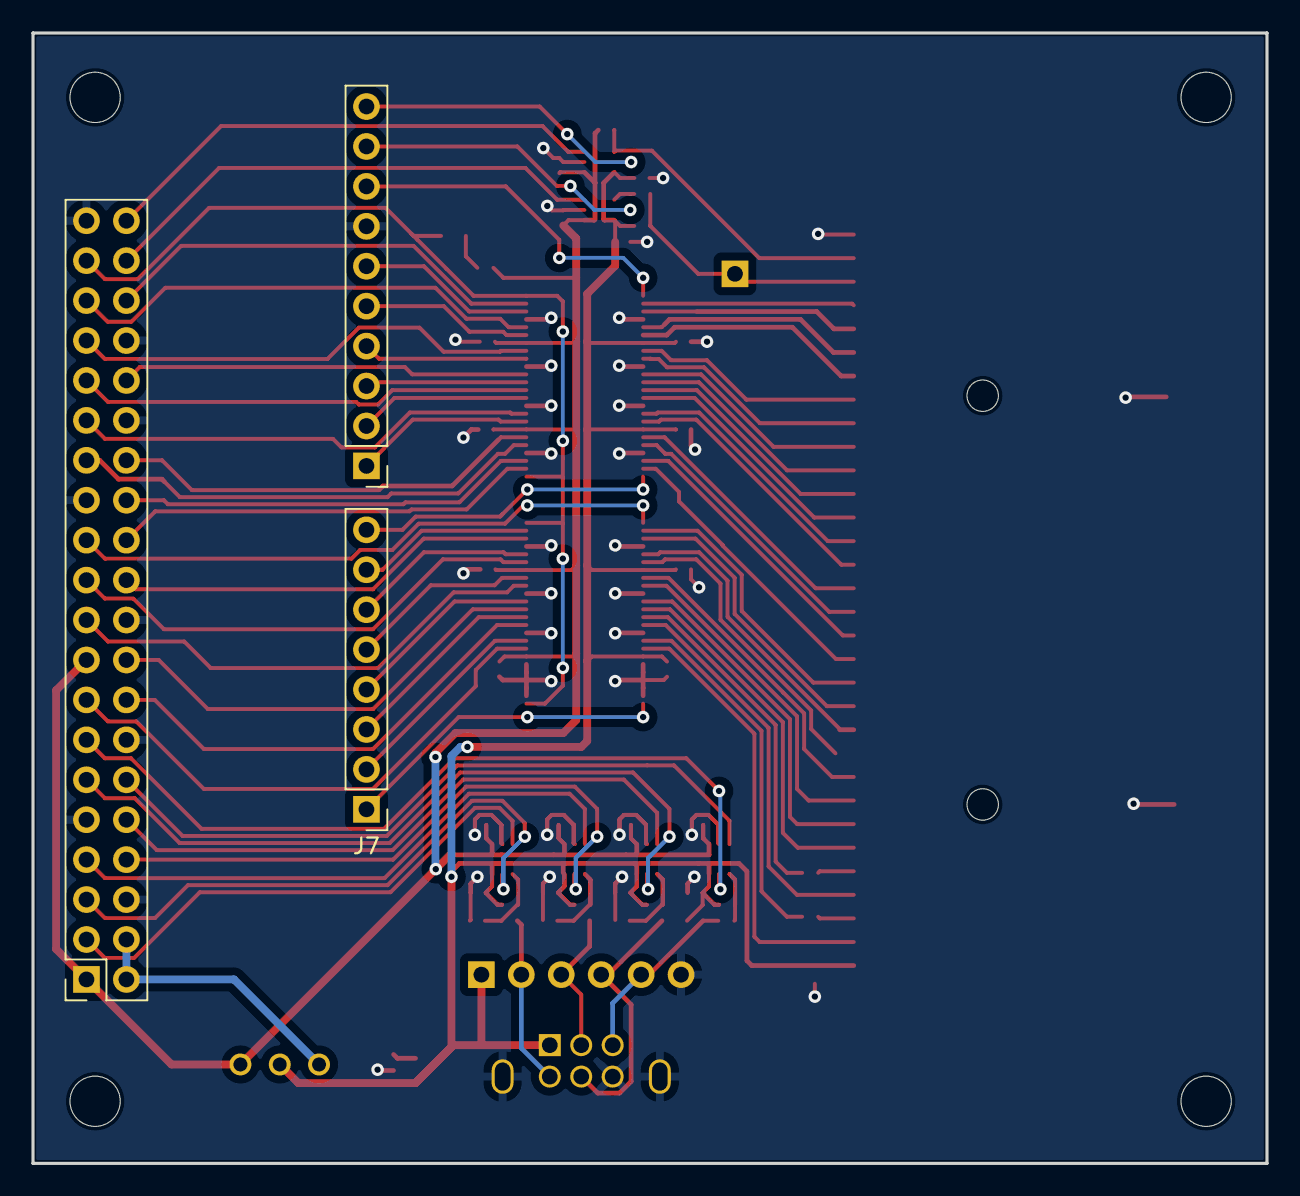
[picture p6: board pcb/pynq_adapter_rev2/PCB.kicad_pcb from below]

Board: 2 copper layers, 78.5 x 71.9 mm, 63 parts (3 on the bottom side), 92 nets.

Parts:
C1, C3, C4: 100pF; C_0402_1005Metric
C2, C5, C6, C7, C8, C9, C10, C11, C12, C13, C14, C15, C16, C17, C18, C19, C20, C21, C22, C23, C24: 0.1uF; C_0402_1005Metric
D1, D2: LED; LED_0603_1608Metric
H1, H2, H3, H4: MountingHole; MountingHole_3.2mm_M3
J1: GameBoy_LinkPort; GameBoy_LinkPort_MGB_Horizontal
J2: LinkPort_Breakout; PinHeader_1x06_P2.54mm_Vertical
J3: GBA_Cartridge_Slot; GameBoy_Cartridge_AGS_1x32-1MP_P1.50mm_Socket_Horizontal
J4: Conn_01x01; PinHeader_1x01_P2.54mm_Vertical
J5: Raspberry Pi 2x20 Connector; PinSocket_2x20_P2.54mm_Vertical
J6: Conn_01x10; PinHeader_1x10_P2.54mm_Vertical
J7: Conn_01x08; PinHeader_1x08_P2.54mm_Vertical
R1, R10: 100k; R_0402_1005Metric
R2, R3, R4, R5: 330R; R_0402_1005Metric
R6, R9: 47R; R_0402_1005Metric
R7: 18k; R_0402_1005Metric
R8: 22R; R_0402_1005Metric
R11, R16: 3.3k; R_0402_1005Metric
R12, R13, R14, R15: 10K; R_0402_1005Metric
SW1: SW_SPDT; EG1218
SW2: SW_Push; SW_Push_1P1T_XKB_TS-1187A
U1, U2: SN74LVCH16T245DGGR; TSSOP-48_6.1x12.5mm_P0.5mm
U3, U4, U5, U6, U7, U8: SN74LVC1T45DCKR; SOT-363_SC-70-6

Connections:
+3.3V: C9.2, C10.2, C11.1, C12.1, C17.2, C18.2, C19.2, C20.2, C23.2, C24.2, J5.1 (GND), J5.17 (3V3), R10.2, R16.1, SW1.1 (A), U1.31 (VCCA), U1.42 (VCCA), U2.31 (VCCA), U2.42 (VCCA), U3.1 (VCCA), U4.1 (VCCA), U5.1 (VCCA), U6.1 (VCCA), U7.1 (VCCA), U8.1 (VCCA)
+5V: J5.2 (5V), J5.4 (5V), SW1.3 (C)
Cart_A0: J3.6 (AD0/A0), U2.12 (1B8)
Cart_A1: J3.7 (AD1/A1), U2.11 (1B7)
Cart_A2: J3.8 (AD2/A2), U2.9 (1B6)
Cart_A3: J3.9 (AD3/A3), U2.8 (1B5)
Cart_A4: J3.10 (AD4/A4), U2.6 (1B4)
Cart_A5: J3.11 (AD5/A5), U2.5 (1B3)
Cart_A6: J3.12 (AD6/A6), U2.3 (1B2)
Cart_A7: J3.13 (AD7/A7), U2.2 (1B1)
Cart_A8: J3.14 (AD8/A8), U1.23 (2B8)
Cart_A9: J3.15 (AD9/A9), U1.22 (2B7)
Cart_A10: J3.16 (AD10/A10), U1.20 (2B6)
Cart_A11: J3.17 (AD11/A11), U1.19 (2B5)
Cart_A12: J3.18 (AD12/A12), U1.17 (2B4)
Cart_A13: J3.19 (AD13/A13), U1.16 (2B3)
Cart_A14: J3.20 (AD14/A14), U1.14 (2B2)
Cart_A15: J3.21 (AD15/A15), U1.13 (2B1)
Cart_D0: J3.22 (A16/D0), U1.12 (1B8)
Cart_D1: J3.23 (A17/D1), U1.11 (1B7)
Cart_D2: J3.24 (A18/D2), U1.9 (1B6)
Cart_D3: J3.25 (A19/D3), U1.8 (1B5)
Cart_D4: J3.26 (A20/D4), U1.6 (1B4)
Cart_D5: J3.27 (A21/D5), U1.5 (1B3)
Cart_D6: J3.28 (A22/D6), U1.3 (1B2)
Cart_D7: J3.29 (A23/D7), U1.2 (1B1)
Cart_PHI: J3.2 (PHI), U2.17 (2B4)
Cart_VIN: J3.31 (~REQ/VIN), R10.1, U7.4 (B)
Cart_~CS: R6.2, U2.13 (2B1)
Cart_~RD: J3.4 (~RD), U2.14 (2B2)
Cart_~RES: R8.2, U8.4 (B)
Cart_~WR: R9.2, U2.16 (2B3)
Dir_A_Hi: J7.8, U1.24 (2DIR)
Dir_A_Lo: J5.23 (Zynq_W10), U2.1 (1DIR)
Dir_Ctrl: J7.1, U2.24 (2DIR)
Dir_D: J6.8, U1.1 (1DIR)
Dir_SC: J5.13 (Zynq_V7), U6.5 (DIR)
Dir_SD: J5.11 (Zynq_U7), U5.5 (DIR)
Dir_SI: J5.8 (Zynq_Y18), U4.5 (DIR)
Dir_SO: J5.5 (Zynq_W19), U3.5 (DIR)
Dir_VIN: J6.10, U7.5 (DIR)
Dir_~RES: J6.9, U8.5 (DIR)
GND: C1.2, C2.2, C3.2, C4.2, C5.1, C6.1, C7.2, C8.2, C9.1, C10.1, C11.2, C12.2, C13.1, C14.1, C15.1, C16.1, C17.1, C18.1, C19.1, C20.1, C21.1, C22.1, C23.1, C24.1, J1.6 (GND), J1.SH, J2.6, J3.32 (GND), J3.MP, J5.6 (GND), J5.9 (GND), J5.14 (GND), J5.20 (GND), J5.25 (GND), J5.30 (GND), J5.34 (GND), J5.39 (GND), J6.7, R11.1, U1.4 (GND), U1.10 (GND), U1.15 (GND), U1.21 (GND), U1.28 (GND), U1.34 (GND), U1.39 (GND), U1.45 (GND), U2.4 (GND), U2.10 (GND), U2.15 (GND), U2.19 (2B5), U2.20 (2B6), U2.21 (GND), U2.22 (2B7), U2.23 (2B8), U2.26 (2A8), U2.27 (2A7), U2.28 (GND), U2.29 (2A6), U2.30 (2A5), U2.34 (GND), U2.39 (GND), U2.45 (GND), U3.2 (GND), U4.2 (GND), U5.2 (GND), U6.2 (GND), U7.2 (GND), U8.2 (GND)
Link_SC: R5.2, R15.2, U6.4 (B)
Link_SD: C1.1, R4.2, R14.2, U5.4 (B)
Link_SI: C3.1, R3.2, R13.2, U4.4 (B)
Link_SO: C4.1, R2.2, R12.2, U3.4 (B)
unnamed: D1.1 (K), R11.2
unnamed: D2.2 (A), R16.2
unnamed: J1.5 (SC), J2.5, R1.1, R5.1
unnamed: J1.4 (SD), J2.4, R4.1
unnamed: J1.3 (SI), J2.3, R3.1
unnamed: J1.2 (SO), J2.2, R2.1
unnamed: J3.5 (~CS1/~CS), R6.1
unnamed: J3.30 (~CS2/~RES), J4.1, R7.1, R8.1
unnamed: J3.3 (~WR), R9.1
Out_A0: J5.18 (Zynq_U18), U2.37 (1A8)
Out_A1: J7.4, U2.38 (1A7)
Out_A2: J5.19 (Zynq_V8), U2.40 (1A6)
Out_A3: J7.5, U2.41 (1A5)
Out_A4: J5.21 (Zynq_V10), U2.43 (1A4)
Out_A5: J7.6, U2.44 (1A3)
Out_A6: J5.22 (Zynq_U19), U2.46 (1A2)
Out_A7: J7.7, U2.47 (1A1)
Out_A8: J5.24 (Zynq_F19), U1.26 (2A8)
Out_A9: J5.26 (Zynq_F20), U1.27 (2A7)
Out_A10: J5.27 (Zynq_Y16), U1.29 (2A6)
Out_A11: J5.28 (Zynq_Y17), U1.30 (2A5)
Out_A12: J6.1, U1.32 (2A4)
Out_A13: J5.29 (Zynq_Y6), U1.33 (2A3)
Out_A14: J6.2, U1.35 (2A2)
Out_A15: J5.31 (Zynq_Y7), U1.36 (2A1)
Out_D0: J6.3, U1.37 (1A8)
Out_D1: J5.32 (Zynq_B20), U1.38 (1A7)
Out_D2: J6.4, U1.40 (1A6)
Out_D3: J5.33 (Zynq_W8), U1.41 (1A5)
Out_D4: J6.5, U1.43 (1A4)
Out_D5: J5.35 (Zynq_Y8), U1.44 (1A3)
Out_D6: J6.6, U1.46 (1A2)
Out_D7: J5.36 (Zynq_B19), U1.47 (1A1)
Out_PHI: J5.15 (Zynq_U8), U2.32 (2A4)
Out_SC: J5.12 (Zynq_C20), U6.3 (A)
Out_SD: J5.10 (Zynq_Y19), U5.3 (A)
Out_SI: J5.7 (Zynq_V6), U4.3 (A)
Out_SO: J5.3 (Zynq_W18), U3.3 (A)
Out_VIN: J5.40 (Zynq_Y9), U7.3 (A)
Out_~CS: J7.3, U2.36 (2A1)
Out_~RD: J5.16 (Zynq_W6), U2.35 (2A2)
Out_~RES: J5.38 (Zynq_A20), U8.3 (A)
Out_~WR: J7.2, U2.33 (2A3)
VDD: C2.1, C5.2, C6.2, C7.1, C8.1, C13.2, C14.2, C15.2, C16.2, C21.2, C22.2, D1.2 (A), J1.1 (VDD), J2.1, J3.1 (VDD), R1.2, R7.2, R12.1, R13.1, R14.1, R15.1, SW1.2 (B), U1.7 (VCCB), U1.18 (VCCB), U2.7 (VCCB), U2.18 (VCCB), U3.6 (VCCB), U4.6 (VCCB), U5.6 (VCCB), U6.6 (VCCB), U7.6 (VCCB), U8.6 (VCCB)
~OE: D2.1 (K), J5.37 (Zynq_W9), U1.25 (2~OE), U1.48 (1~OE), U2.25 (2~OE), U2.48 (1~OE)

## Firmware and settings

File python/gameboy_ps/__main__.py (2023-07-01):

#!/usr/bin/env python3

"""
Zynq PS side of the Gameboy, using the Pynq API to provide input and ROM loading.

Must be run as root.
"""

import logging
logging.basicConfig(format='[%(asctime)s][%(levelname)s] %(message)s', level=logging.DEBUG)
import sys
from pathlib import Path

from . import system

rom_directory = Path(sys.argv[1])
system = system.System(rom_directory)
system.start()

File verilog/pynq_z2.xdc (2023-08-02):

# Copyright (C) 2022 Xilinx, Inc
# SPDX-License-Identifier: BSD-3-Clause

## Enable bitstream compression
# set_property BITSTREAM.GENERAL.COMPRESS True [current_design]

## Clock signal 125 MHz
# set_property -dict { PACKAGE_PIN H16   IOSTANDARD LVCMOS33 } [get_ports { clk_125mhz }]; #IO_L13P_T2_MRCC_35 Sch=sysclk
# create_clock -add -name clk_125mhz -period 8.00 -waveform {0 4} [get_ports { clk_125mhz }];

## Switches
set_property -dict {PACKAGE_PIN M20 IOSTANDARD LVCMOS33} [get_ports {switches[0]}]
set_property -dict {PACKAGE_PIN M19 IOSTANDARD LVCMOS33} [get_ports {switches[1]}]

## Audio
# set_property -dict {PACKAGE_PIN U9 IOSTANDARD LVCMOS33} [get_ports IIC_1_scl_io]
# set_property PULLUP true [get_ports IIC_1_scl_io];
# set_property -dict {PACKAGE_PIN T9 IOSTANDARD LVCMOS33} [get_ports IIC_1_sda_io]
# set_property PULLUP true [get_ports IIC_1_sda_io];
# set_property -dict { PACKAGE_PIN U5   IOSTANDARD LVCMOS33 } [get_ports audio_clk_10MHz]; 
# set_property -dict { PACKAGE_PIN R18   IOSTANDARD LVCMOS33 } [get_ports bclk]; 
# set_property -dict { PACKAGE_PIN T17   IOSTANDARD LVCMOS33 } [get_ports lrclk]; 
# set_property -dict { PACKAGE_PIN G18   IOSTANDARD LVCMOS33 } [get_ports sdata_o];
# set_property -dict { PACKAGE_PIN F17   IOSTANDARD LVCMOS33 } [get_ports sdata_i]; 
# set_property -dict { PACKAGE_PIN M17   IOSTANDARD LVCMOS33 } [get_ports {codec_addr[0]}]
# set_property -dict { PACKAGE_PIN M18   IOSTANDARD LVCMOS33 } [get_ports {codec_addr[1]}]

## Buttons
set_property -dict {PACKAGE_PIN D19 IOSTANDARD LVCMOS33} [get_ports {buttons[0]}]
set_property -dict {PACKAGE_PIN D20 IOSTANDARD LVCMOS33} [get_ports {buttons[1]}]
set_property -dict {PACKAGE_PIN L20 IOSTANDARD LVCMOS33} [get_ports {buttons[2]}]
set_property -dict {PACKAGE_PIN L19 IOSTANDARD LVCMOS33} [get_ports {buttons[3]}]

## LEDs
set_property -dict {PACKAGE_PIN R14 IOSTANDARD LVCMOS33} [get_ports {leds[0]}]
set_property -dict {PACKAGE_PIN P14 IOSTANDARD LVCMOS33} [get_ports {leds[1]}]
set_property -dict {PACKAGE_PIN N16 IOSTANDARD LVCMOS33} [get_ports {leds[2]}]
set_property -dict {PACKAGE_PIN M14 IOSTANDARD LVCMOS33} [get_ports {leds[3]}]

## RGBLEDs
# set_property -dict { PACKAGE_PIN L15   IOSTANDARD LVCMOS33 } [get_ports { rgbleds_6bits_tri_o[0] }]; 
# set_property -dict { PACKAGE_PIN G17   IOSTANDARD LVCMOS33 } [get_ports { rgbleds_6bits_tri_o[1] }]; 
# set_property -dict { PACKAGE_PIN N15   IOSTANDARD LVCMOS33 } [get_ports { rgbleds_6bits_tri_o[2] }]; 
# set_property -dict { PACKAGE_PIN G14   IOSTANDARD LVCMOS33 } [get_ports { rgbleds_6bits_tri_o[3] }];
# set_property -dict { PACKAGE_PIN L14   IOSTANDARD LVCMOS33 } [get_ports { rgbleds_6bits_tri_o[4] }]; 
# set_property -dict { PACKAGE_PIN M15   IOSTANDARD LVCMOS33 } [get_ports { rgbleds_6bits_tri_o[5] }]; 

## HDMI TX
set_property -dict {PACKAGE_PIN L17 IOSTANDARD TMDS_33} [get_ports hdmi_out_clk_n]
set_property -dict {PACKAGE_PIN L16 IOSTANDARD TMDS_33} [get_ports hdmi_out_clk_p]
set_property -dict {PACKAGE_PIN K18 IOSTANDARD TMDS_33} [get_ports {hdmi_out_data_n[0]}]
set_property -dict {PACKAGE_PIN K17 IOSTANDARD TMDS_33} [get_ports {hdmi_out_data_p[0]}]
set_property -dict {PACKAGE_PIN J19 IOSTANDARD TMDS_33} [get_ports {hdmi_out_data_n[1]}]
set_property -dict {PACKAGE_PIN K19 IOSTANDARD TMDS_33} [get_ports {hdmi_out_data_p[1]}]
set_property -dict {PACKAGE_PIN H18 IOSTANDARD TMDS_33} [get_ports {hdmi_out_data_n[2]}]
set_property -dict {PACKAGE_PIN J18 IOSTANDARD TMDS_33} [get_ports {hdmi_out_data_p[2]}]
set_property -dict {PACKAGE_PIN R19 IOSTANDARD LVCMOS33} [get_ports {hdmi_out_hpd[0]}]

## Pmoda
## RPi GPIO 7-0 are shared with pmoda_rpi_gpio_tri_io[7:0]
# set_property -dict {PACKAGE_PIN Y19 IOSTANDARD LVCMOS33} [get_ports {pmoda_rpi_gpio_tri_io[1]}]
# set_property -dict {PACKAGE_PIN Y18 IOSTANDARD LVCMOS33} [get_ports {pmoda_rpi_gpio_tri_io[0]}]
# set_property -dict {PACKAGE_PIN Y17 IOSTANDARD LVCMOS33} [get_ports {pmoda_rpi_gpio_tri_io[3]}]
# set_property -dict {PACKAGE_PIN Y16 IOSTANDARD LVCMOS33} [get_ports {pmoda_rpi_gpio_tri_io[2]}]
# set_property -dict {PACKAGE_PIN U19 IOSTANDARD LVCMOS33} [get_ports {pmoda_rpi_gpio_tri_io[5]}]
# set_property -dict {PACKAGE_PIN U18 IOSTANDARD LVCMOS33} [get_ports {pmoda_rpi_gpio_tri_io[4]}]
# set_property -dict {PACKAGE_PIN W19 IOSTANDARD LVCMOS33} [get_ports {pmoda_rpi_gpio_tri_io[7]}]
# set_property -dict {PACKAGE_PIN W18 IOSTANDARD LVCMOS33} [get_ports {pmoda_rpi_gpio_tri_io[6]}]
# set_property PULLUP true [get_ports {pmoda_rpi_gpio_tri_io[2]}]
# set_property PULLUP true [get_ports {pmoda_rpi_gpio_tri_io[3]}]
# set_property PULLUP true [get_ports {pmoda_rpi_gpio_tri_io[6]}]
# set_property PULLUP true [get_ports {pmoda_rpi_gpio_tri_io[7]}]
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

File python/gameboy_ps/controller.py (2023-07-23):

from abc import ABC
from enum import Enum
import logging
from typing import Callable
import threading
import time

from xbox360controller import Xbox360Controller
from smbus2 import SMBus

class Button(Enum):
    START = 0
    SELECT = 1
    B = 2
    A = 3
    DOWN = 4
    UP = 5
    LEFT = 6
    RIGHT = 7
    HOME = 8

ControllerCallback = Callable[[Button, bool], None]


class Controller:
    pass


class XboxController(Controller):
    def __init__(self, callback: ControllerCallback):
        def on_hat_moved(axis):
            callback(Button.LEFT, axis.x < 0)
            callback(Button.RIGHT, axis.x > 0)
            callback(Button.DOWN, axis.y < 0)
            callback(Button.UP, axis.y > 0)

        try:
            controller = Xbox360Controller(0, axis_threshold=-1)
        except:
            logging.warning("No Xbox controllers found")
            return

        # A and B are swapped due to the different locations on the Xbox controller vs the Gameboy joypad
        controller.button_a.when_pressed = lambda _: callback(Button.B, True)
        controller.button_a.when_released = lambda _: callback(Button.B, False)
        controller.button_b.when_pressed = lambda _: callback(Button.A, True)
        controller.button_b.when_released = lambda _: callback(Button.A, False)
        controller.button_select.when_pressed = lambda _: callback(Button.SELECT, True)
        controller.button_select.when_released = lambda _: callback(Button.SELECT, False)
        controller.button_start.when_pressed = lambda _: callback(Button.START, True)
        controller.button_start.when_released = lambda _: callback(Button.START, False)
        controller.button_mode.when_pressed = lambda _: callback(Button.HOME, True)
        controller.button_mode.when_released = lambda _: callback(Button.HOME, False)
        controller.hat.when_moved = on_hat_moved
        logging.info("Initialized Xbox controller")


class WiiClassicController(Controller):
    """Wii classic controller over I2C"""
    I2C_ADDR = 0x52
    I2C_INIT_DELAY = 0.1
    I2C_READ_DELAY = 0.002
    I2C_BUS = 0
    I2C_CONNECT_DELAY = 2.0
    POLL_RATE = 100

    def __init__(self, callback: ControllerCallback):
        self._callback = callback
        self._bus = SMBus(self.I2C_BUS)

        t = threading.Thread(target=self._event_loop)
        t.start()

    def _event_loop(self):
        while True:
            # Attempt to initialize controller
            while True:
                try:
                    self._bus.read_byte(self.I2C_ADDR)

                    self._bus.write_byte_data(self.I2C_ADDR, 0xF0, 0x55)
                    time.sleep(self.I2C_INIT_DELAY)
                    self._bus.write_byte_data(self.I2C_ADDR, 0xFB, 0x00)
                    time.sleep(self.I2C_INIT_DELAY)

                    self._bus.write_byte(self.I2C_ADDR, 0xFE)
                    time.sleep(self.I2C_READ_DELAY)
                    controller_id = self._bus.read_byte(self.I2C_ADDR)
                    logging.info("Connected to Wii Classic Controller: ID=%d", controller_id)
                    break
                except OSError as error:
                    time.sleep(self.I2C_CONNECT_DELAY)

            # Poll controller
            while True:
                try:
                    self._bus.write_byte(self.I2C_ADDR, 0x0)
                    time.sleep(self.I2C_READ_DELAY)
                    data = [self._bus.read_byte(self.I2C_ADDR) for _ in range(0, 8)]

                    self._callback(Button.A, not bool(data[5] & (1 << 4)))
                    self._callback(Button.B, not bool(data[5] & (1 << 6)))
                    self._callback(Button.START, not bool(data[4] & (1 << 2)))
                    self._callback(Button.SELECT, not bool(data[4] & (1 << 4)))
                    self._callback(Button.HOME, not bool(data[4] & (1 << 3)))
                    self._callback(Button.LEFT, not bool(data[5] & (1 << 1)))
                    self._callback(Button.RIGHT, not bool(data[4] & (1 << 7)))
                    self._callback(Button.UP, not bool(data[5] & (1 << 0)))
                    self._callback(Button.DOWN, not bool(data[4] & (1 << 6)))

                    time.sleep(1.0 / self.POLL_RATE)
                except OSError:
                    logging.info("Disconnected from Wii Classic Controller")
                    break


CONTROLLER_LISTENERS = [
    XboxController,
    WiiClassicController,
]

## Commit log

2022-02-07 Initial microcode generation and state machine
    [microcode.csv]
2022-02-07 Add basic program execution in testbench
    [microcode.csv]
2022-02-09 Add initial register file, implement 'load immediate to reg8' to test it
    [microcode.csv]
2022-02-10 Add basic ALU, implement LD r, r
    [microcode.csv]
2022-02-10 Implement load to/from (HL) instructions
    [microcode.csv]
2022-02-10 Refactor register writing to use RegOp to support HL+ and HL-
    [microcode.csv]
2022-02-10 Add temp registers, implement LD (HL),n
    [microcode.csv]
2022-02-11 Add ability to assemble ROMs with RGBDS and run them
2022-02-11 Implement 16-bit immediate load, inc/dec HL/A loads
    [microcode.csv]
2022-02-11 Implement ALU A,n instructions
    [microcode.csv]
2022-02-11 Implement ALU A,r and ALU A,(HL) instructions
    [microcode.csv]
2022-02-12 Implement JP nn
    [microcode.csv]
2022-02-12 Implement JP HL
    [microcode.csv]
2022-02-12 Implement JP with condition
    [microcode.csv]
2022-02-13 Refactor ALU operations to always have Op1=A
    [microcode.csv]
2022-02-13 Implement LD (rr), A and LD A, (rr)
    [microcode.csv]
2022-02-13 Implement load A to/from immediate address
    [microcode.csv]
2022-02-13 Implement LDH instructions
    [microcode.csv]
2022-02-13 Refactor to have an incrementer/decrementer address calculation unit
    [microcode.csv]
2022-02-13 Implement 16-bit inc/dec
    [microcode.csv]
2022-02-13 Implement 'LD (nn), SP'
    [microcode.csv]
2022-02-13 Remove some redundant states
    [microcode.csv]
2022-02-14 Implement LD SP, HL
    [microcode.csv]
2022-02-14 Implement PUSH/POP (for registers other than AF)
    [microcode.csv]
2022-02-15 Refactor PC increment to use incrementer
    [microcode.csv]
2022-02-17 Implement 16-bit HL add
    [microcode.csv]
2022-02-17 Implement 16-bit signed adds (with SP and HL)
    [microcode.csv]
2022-02-18 Implement PUSH/POP AF
    [microcode.csv]
2022-02-18 Implement JR
    [microcode.csv]
2022-02-18 Implement conditional JR
    [microcode.csv]
2022-02-18 Implement CALL/RET (conditional and regular)
    [microcode.csv]
2022-02-21 Implement 8-bit INC and DEC
    [microcode.csv]
2022-02-21 Implement unary accumulator/flag ops (except DAA)
    [microcode.csv]
2022-02-21 Implement dispatch for CB-prefixed instructions
    [microcode.csv]
2022-02-21 Implement CB-prefixed shifts/rotates
    [microcode.csv]
2022-02-21 Implement CB-prefixed single-bit operations
    [microcode.csv]
2022-02-21 Implement EI/DI
    [microcode.csv]
2022-02-21 Implement RETI
    [microcode.csv]
2022-02-26 Implement RST
    [microcode.csv]
2022-03-01 Sort of implement STOP instruction
    [microcode.csv]
2022-04-08 Move most CPU files to cpu/ subdirectory
    [microcode.csv]
2022-04-10 Switch CPU mem_enable to only happen for one t-cycle
2022-04-18 Keep track of scanlines and cycles
2023-04-03 Start Chisel conversion, control and alu complete
    [microcode.csv]
2023-04-07 cpu: Add initial interrupt test (failing)
2023-04-07 cpu: Start implementing interrupts (not working)
    [microcode.csv]
2023-04-13 Initial timer implementation
2023-04-13 Making timer work with blargg test
2023-04-13 cpu: Exit from halt on interrupt
2023-04-13 cpu: Add HALT tests to interrupt tests
2023-04-13 ppu: Add interrupts
2023-04-16 Implement OAM dma
2023-04-18 sim: Implement MBC3 (without timer)
2023-04-25 sim: Switch to double buffering to prevent tearing
2023-04-25 timer: Only reset TIMA when an increment causes it to overflow
    Previously, the overflow condition was based on (TIMA + 1) overflowing,
    regardless of whether or not TIMA would actually be incremented this
    cycle. This meant that TIMA reloaded any time it had a value of 0xFF,
    rather than waiting for the next increment.
2023-04-26 sim: Sample APU and output audio
2023-04-27 sim: Reinterpret audio samples as signed 10-bit audio
2023-04-28 apu: Refactor into separate FrameSequencer module
2023-04-30 cpu: Switch control table and dispatch table to use a ROM for Verilator performance
2023-04-30 pynq-z2: Add test counter with fusesoc
2023-05-01 pynq-z2: Add HDMI sample output
2023-05-01 pynq-z2: Improve audio output, allow turning off via switch and tone via buttons
2023-05-05 sim: Add cmd-R to reset
    [main.cpp]
2023-05-05 build: Make fusesoc use Chisel as a generator
2023-05-07 zynq: Switch to HP0 port, add AXI3->AXI4-Lite converter
2023-05-09 Test out the AxiLiteInitiator with Pynq
    It works, but doesn't quite access memory correctly.
    It's as though all reads (which are 32-bit) are forcibly 64-bit aligned.
    So two successive 32-bit reads read the same thing, then the next jumps
    up by 8 bytes.
    This seems to be an issue with the AXI_HP0 port. If I switch it to the
    AXI_GP0 port it works fine (with maybe a cycle more of latency?).
    The AXI_HP0 port needs to be configured to act in 32-bit mode. It's in
    64 by default. This fixes it:
    devmem2 0xf8008000 w 1
    devmem2 0xf8008014 w 1
    And some sources say that this should only be done before the bitstream
    is loaded, but it actually seems to work even while the bitstream is
    running.
2023-05-09 Switch to using HP_AXI in 64-bit mode directly
2023-05-11 Switch to ZynqGameboy, add registers to see CPU state and pause gameboy
2023-05-12 sim: Switch to SimGameboy wrapper
2023-05-15 Implement Serial for ZynqGameboy
    Note that this doesn't quite work with the TXS0108B. The serial output
    when a cable isn't connected is correct, but when a cable is connected
    the capacitance (presumably) throws things off and makes the outputs
    oscillate and not be usable.
    Directly connecting the Pynq-Z2 pins seems to work some of the time.
    Presumably a better circuit would be better, maybe just open drain using
    some transistors directly.
    [pynq_z2.xdc]
2023-05-15 Attempt to address timing issues
    [pynq_z2.xdc]
2023-05-17 Rework clocking in ZynqGameboy to address timing issues
    Previously, there were several asynchronous clocks:
    * 100 MHz clock from PS, used to clock AXI target and initiator
    and as the input clock to the PLL:
    * ~ 8 MHz clock used to make the gameboy clock
    * The 25.2 and 126 MHz clocks used for HDMI output
    There were lots of CDC issues between:
    * AXI target config registers (100 MHz) and the Gameboy (8 MHz)
    (both in terms of readable properties, e.g. stat registers, and
    writable properties, like the 'running' flag)
    * Gameboy emulated cartridge (8 Mhz) and the AXI initiator data source
    (100 MHz)
    This commit switches how the clocks are generated and used. The 100 MHz
    clock from the PS i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
2023-05-19 Handle framebuffer within ZynqGameboy
2023-06-10 Allow Zynq PS to update framebuffer
2023-06-10 Expose PS i2c-0 to PMOD B via EMIO
2023-06-11 Switch to using logging in Python
2023-06-11 Allow switching between emulated and physical cartridge in same bitstream
2023-06-13 ** start working on framebuffer blit
2023-06-30 Rework Python, put Gameboy in separate class
    [__main__.py, controller.py, gameboy.py]
2023-06-30 Add copy framebuffer method
2023-06-30 Update framebuffer copy to work with Pillow's I mode instead of I;16
2023-07-01 Deduplicate button events
2023-07-01 Persist battery-backed RAM when in-game menu is opened
2023-07-03 Add error modal in ROM load screen
    [gameboy.py, ui.py]
2023-07-07 Add xbox home button
2023-07-14 Fix link cable
2023-07-15 README: Add notes about running fusesoc and setting up Vivado IP cache
2023-07-16 Switch SimpleCache to use memory instead of registers, make it bigger
2023-07-17 Implement CGB VRAM DMA
2023-07-19 Blank Zynq framebuffer when LCD is off
2023-07-19 Add basic stats display (with # clocks overflow issues)
    [gameboy.py, ui.py]
2023-07-23 Don't poll I2C controller so frequently upon failure
    [controller.py]
2023-07-23 Fix bug where PPU interrupts would fire on multiple cycles
2023-07-23 Fix bug where a series of HALTs would skip through all of them on an interrupt
    [microcode.csv]
2023-07-23 Fix rom select list position memory
    [ui.py]
2023-09-28 Add PCB design files
    [PCB.kicad_pcb, PCB.kicad_sch, level_shifters.kicad_sch]

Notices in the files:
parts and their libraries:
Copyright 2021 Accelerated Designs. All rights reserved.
